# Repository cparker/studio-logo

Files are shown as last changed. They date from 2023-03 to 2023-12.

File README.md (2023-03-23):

# Studio Technology Logo

A 3D printed model of the Disney Studio Technology Logo.  Uses individually addressible WS2812B LEDs and an ESP32 microcontroller.

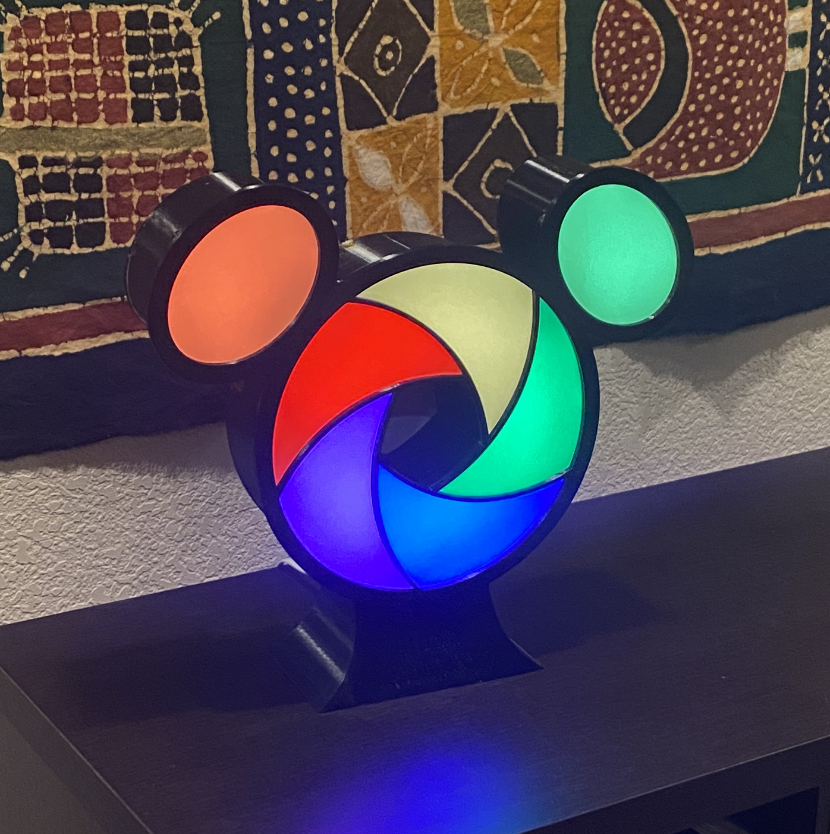
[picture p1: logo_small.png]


## Parts
* vellum (tracing paper) to diffuse the LEDs https://amzn.to/3JvHVWc 
* magnets : Holds the covers on https://amzn.to/3FLLyq5
* LED strips : [AliExpress](https://www.aliexpress.us/item/3256803346805677.html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)
* ESP32 microcontroller : [AliExpress](https://www.aliexpress.us/item/2251832622236364.html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)
* sticker paper : for the inside https://amzn.to/3Zb8XZ1  (or just glue regular white paper)

Parts to Print
* 1x [main frame](./cad/frame.stl)
* 1x [front cover](./cad/studio-logo-face.stl)
* 1x [stand](./cad/studio-logo-stand.stl)
* 1x [L Ear](./cad/ear-L.stl)
* 1x [R Ear](./cad/ear-r.stl)
* 1x [L Ear Cover](./cad/studio-logo-ear-cover-l.stl)
* 1x [R Ear Cover](./cad/studio-logo-ear-cover-r.stl)
* 1x [L Ear Bracket](./cad/studio-logo-ear-brack-l.stl)
* 1x [R Ear Bracket](./cad/studio-logo-ear-brack-r.stl)
* 5x [LED Brackets](./cad/led_bracket.stl)

Optionally print the backs (looks much better with the backs on)
* 1x [back cover](./cad/frame_back.stl)
* 3x [frame back mounts](./cad/main-back-mounts.stl)
* 1x [L ear back](./cad/studio-logo-ear-back-L.stl)
* 1x [R ear back](./cad/studio-logo-ear-back-r.stl)
* 4x [ear back mounts](./cad/ear-back-mount.stl)

Cut sticker paper to fit and line the inside or glue white paper to the inside.  This will help diffuse the light.

Glue magnets into the holes for attaching the front and back covers.  For glueing the magnets I use E6000 https://amzn.to/3ndiRvU .

Cut and glue vellum to the inside of the front cover and ear covers.

Glue the LED strip brackets to the inside of the frame (see cad model photos for guidence)

Wire up the LEDs and ESP32

Mount the LED strips to the brackets (hot glue or screws)

Upload the code to the ESP32

CAD model front
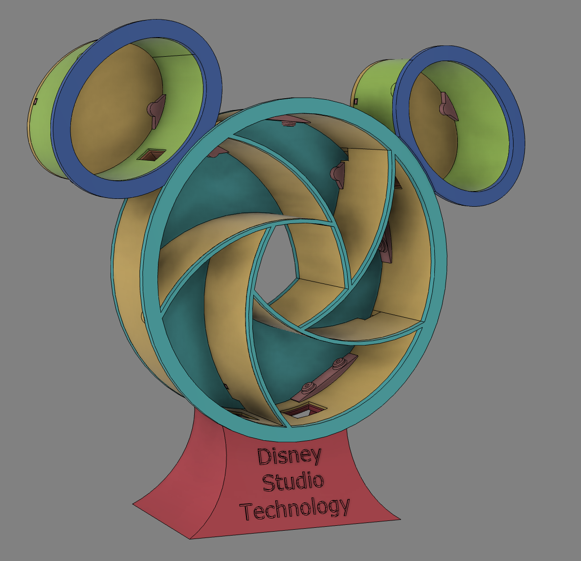
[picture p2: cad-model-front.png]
cad model front

CAD model back
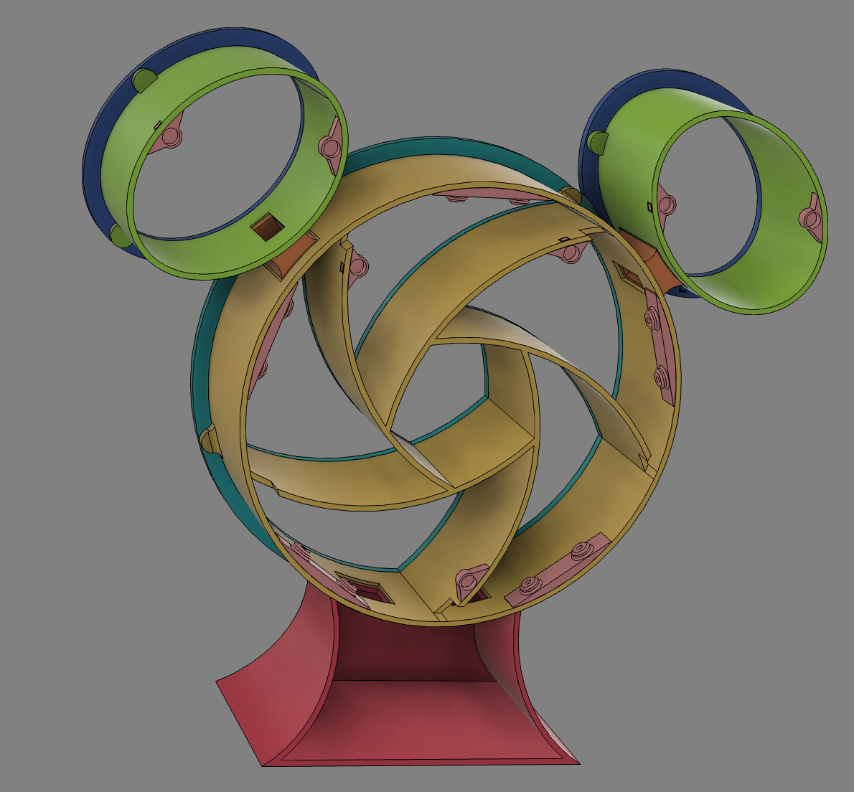
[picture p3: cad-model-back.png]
cad model front


CAD model video</br>

CAD model video (https://youtu.be/u030uRLA1Uc)

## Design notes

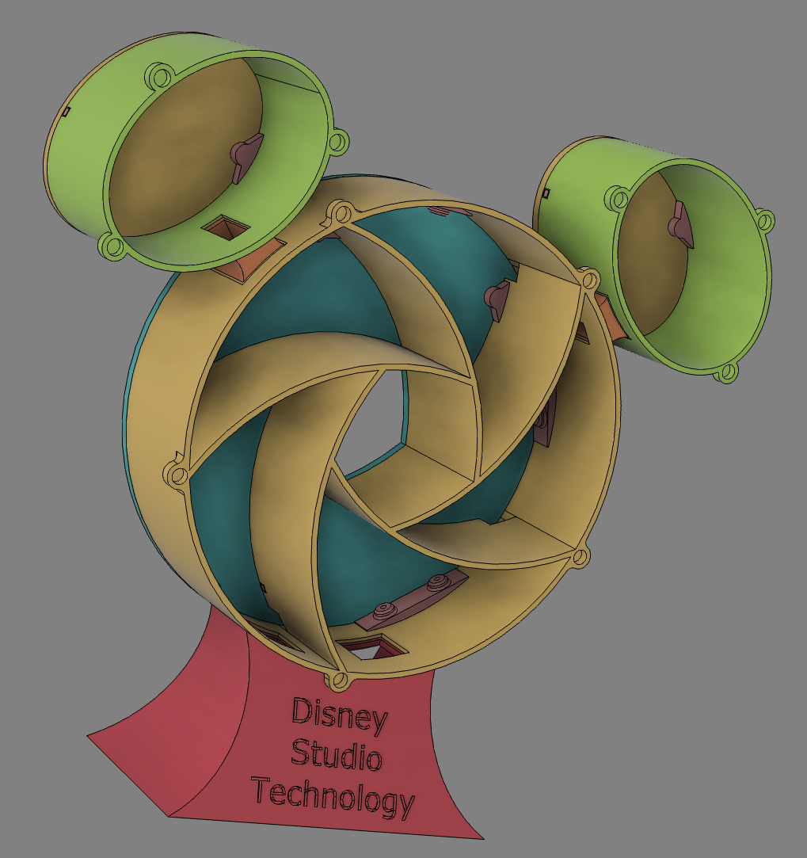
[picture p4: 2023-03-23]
cad-model-front-2.png

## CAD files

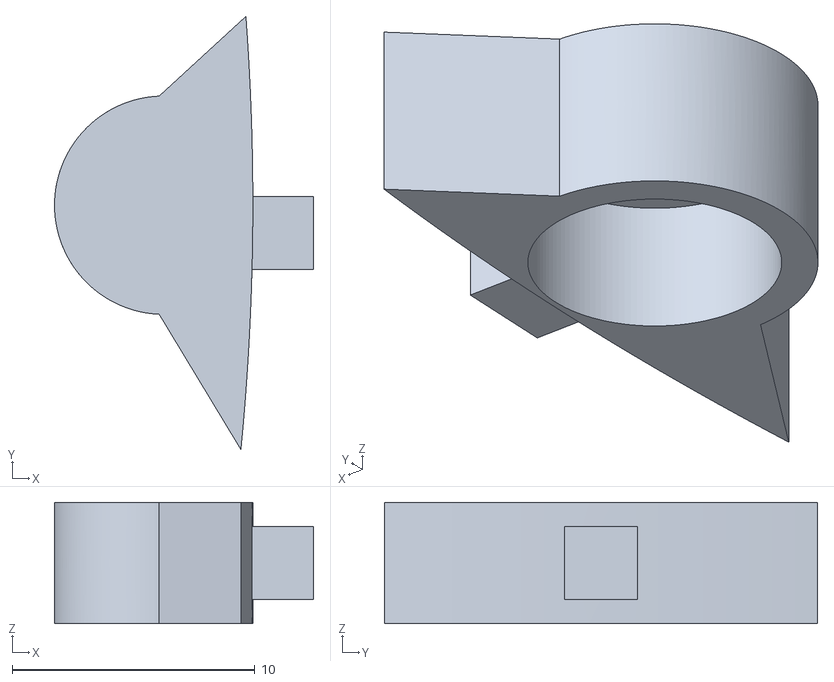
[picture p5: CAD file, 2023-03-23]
cad/main-back-mounts.stl
10.7 x 17.9 x 5.00

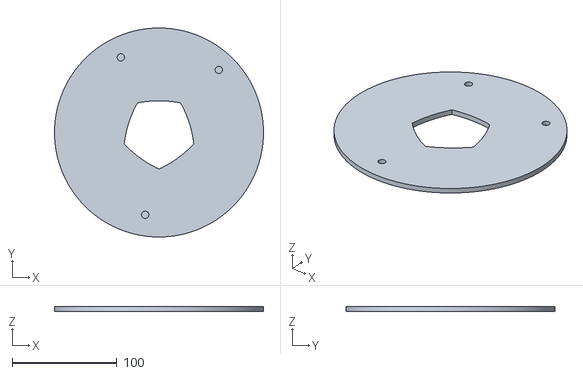
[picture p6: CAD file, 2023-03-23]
cad/frame_back.stl
200.0 x 200.0 x 4.50

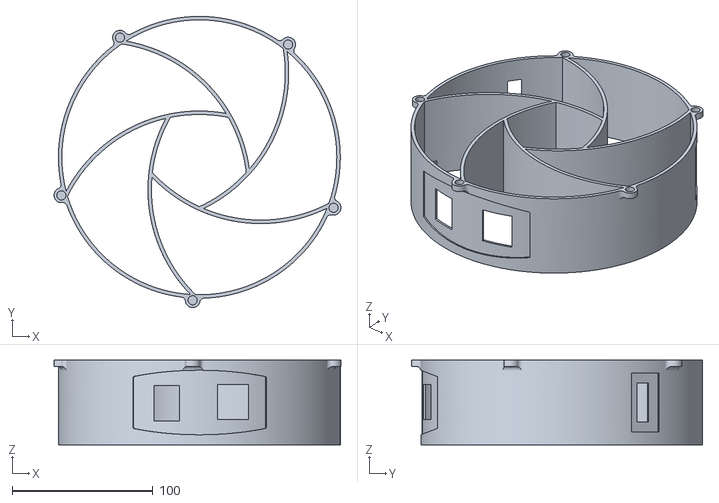
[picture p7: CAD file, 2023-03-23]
cad/frame.stl
203.6 x 206.6 x 60.0

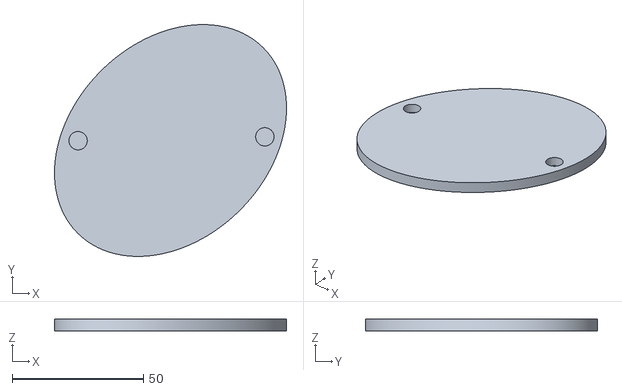
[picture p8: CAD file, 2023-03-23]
cad/studio-logo-ear-back-L.stl
88.4 x 88.3 x 4.50

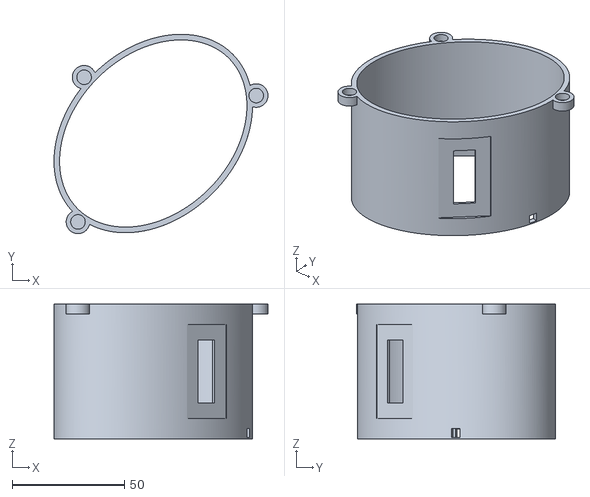
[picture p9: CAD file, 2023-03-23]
cad/ear-L.stl
95.3 x 88.8 x 60.0

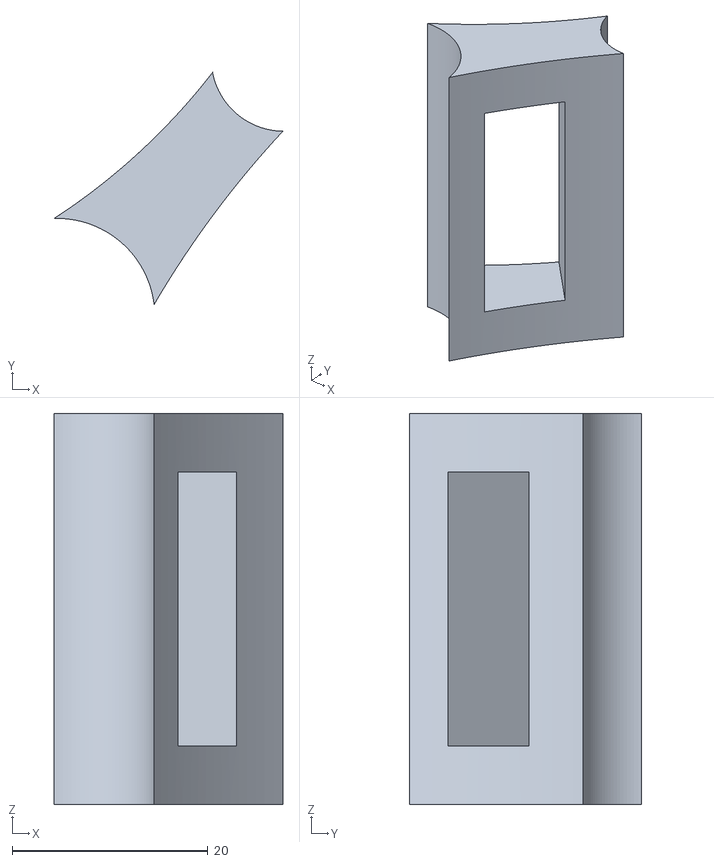
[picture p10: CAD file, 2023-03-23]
cad/studio-logo-ear-brack-l.stl
23.4 x 23.7 x 40.0

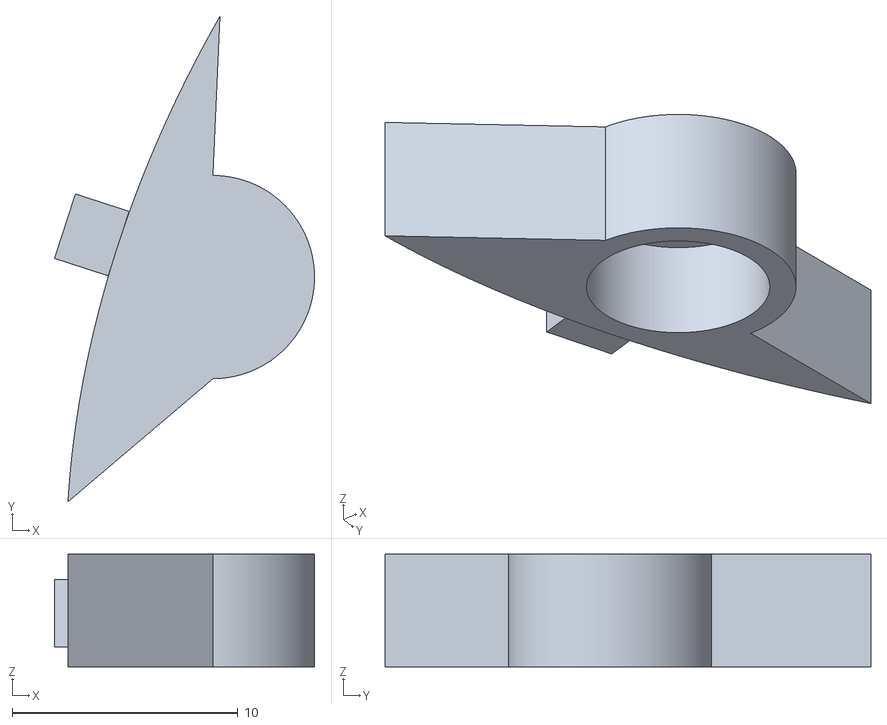
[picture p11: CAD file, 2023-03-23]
cad/ear-back-mount.stl
11.5 x 21.5 x 5.00

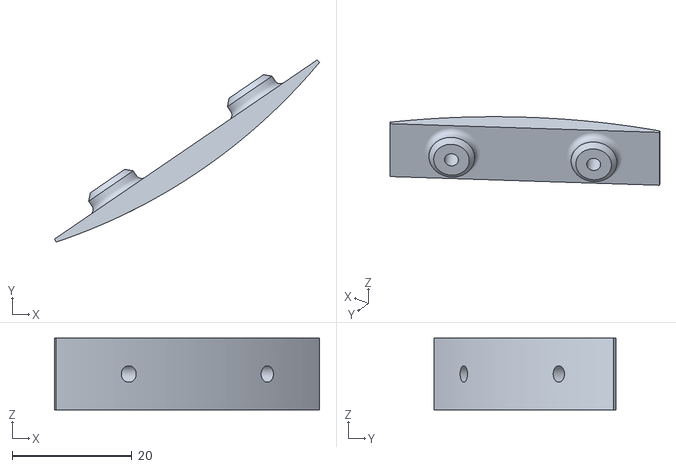
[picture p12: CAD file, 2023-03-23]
cad/led_bracket.stl
44.2 x 30.4 x 12.0

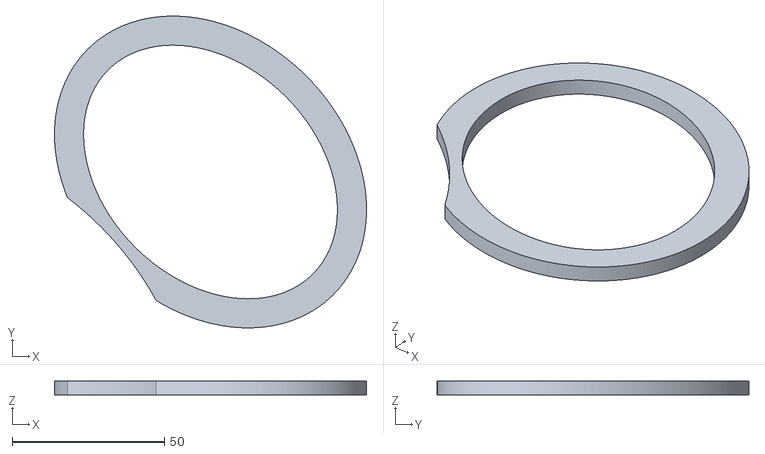
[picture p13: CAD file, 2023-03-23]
cad/studio-logo-ear-cover-r.stl
102.6 x 102.5 x 4.50

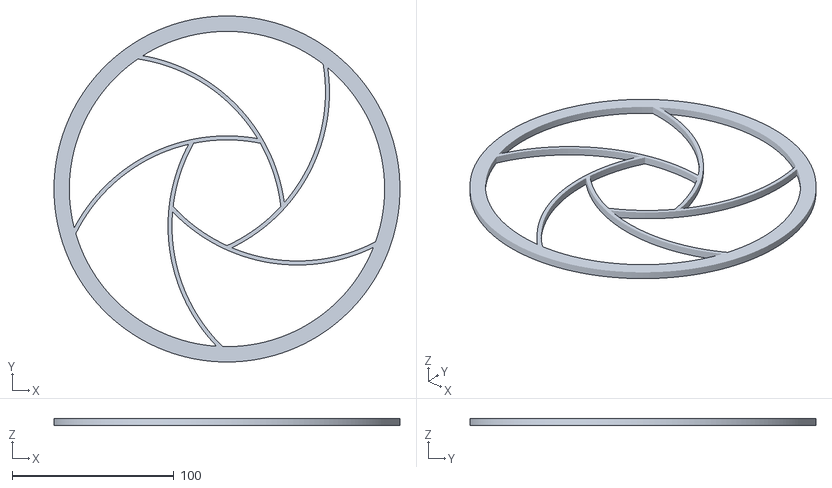
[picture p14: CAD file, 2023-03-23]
cad/studio-logo-face.stl
214.0 x 214.0 x 4.50

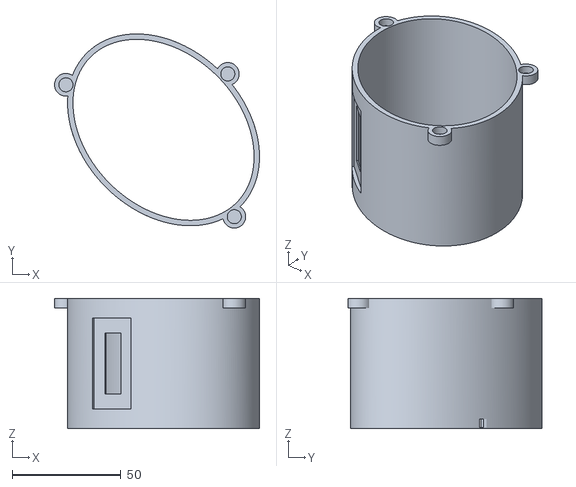
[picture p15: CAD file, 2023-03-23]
cad/ear-r.stl
94.4 x 89.4 x 60.0

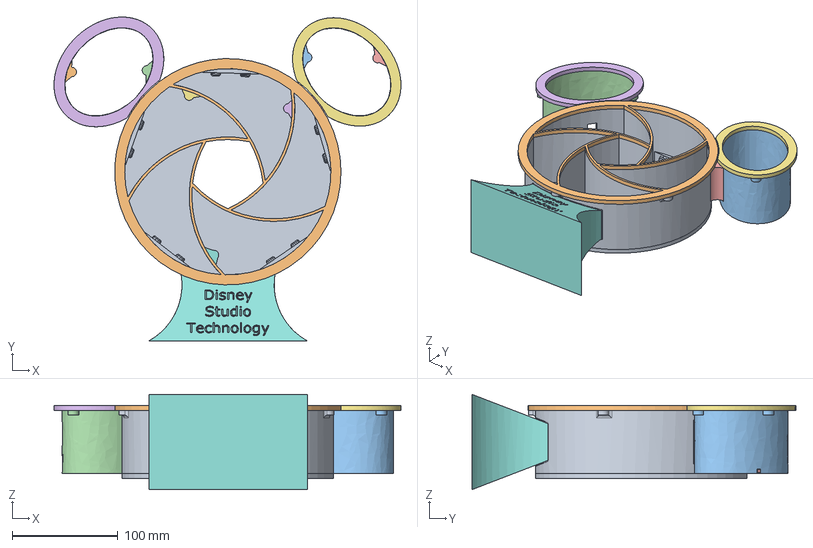
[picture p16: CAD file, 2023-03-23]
cad/studio tech logo.step
328.1 x 306.2 x 90.0 mm
frame
ears
ear brackets
ear covers
stand
led_brackets
back panel mounts
frame back

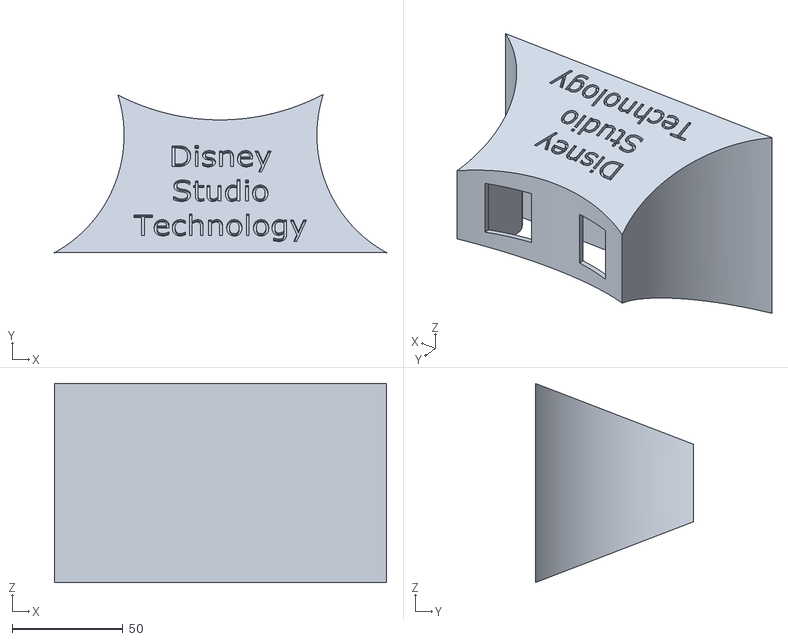
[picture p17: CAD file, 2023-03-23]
cad/studio-logo-stand.stl
150.0 x 71.6 x 90.0

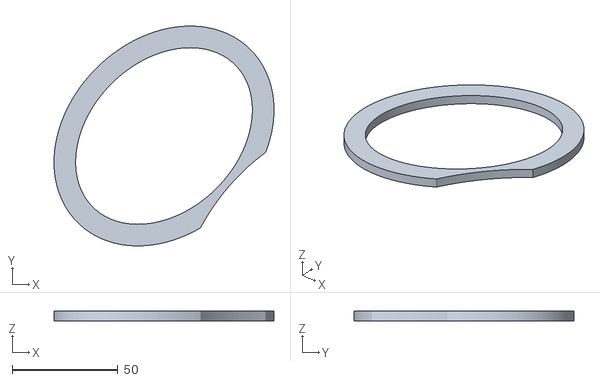
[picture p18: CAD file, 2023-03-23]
cad/studio-logo-ear-cover-l.stl
103.9 x 103.8 x 4.50

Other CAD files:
cad/studio-logo-ear-brack-r.stl
cad/studio-logo-ear-back-r.stl

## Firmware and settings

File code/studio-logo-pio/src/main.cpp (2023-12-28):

#include <ArduinoJson.h>
#include <FastLED.h>
#include <Preferences.h>
#include <PubSubClient.h>
#include <WiFi.h>

#include <algorithm>
#include <map>
#include <string>
#include <vector>

#include "ColorTransition.h"
#include "secrets.h"

// Create an instance of the Preferences library
Preferences preferences;

const int mqtt_port = 1883;

const char* appName = "studio-logo";

// mqtt topic for receiving mode changes
const char* mqtt_topic_mode = "studio-logo/mode";

// mqtt topic for receiving color palette changes
const char* mqtt_topic_palette = "studio-logo/palette";

// LED settings
#define NUM_LEDS 44
#define DATA_PIN 5  // Change this to the GPIO pin you've connected the LEDs to
#define LED_TYPE WS2812B
#define COLOR_ORDER GRB

// this is where state of each LED is stored
CRGB myleds[NUM_LEDS];

// some simple color definitions
CRGB blue(0, 0, 255);
CRGB green(0, 255, 0);
CRGB lighterGreen(20, 255, 20);
CRGB yellow(255, 255, 0);
CRGB red(255, 0, 0);
CRGB orange(255, 165, 0);
CRGB purple(128, 0, 128);
CRGB white(255, 255, 255);

struct LEDSection {
  int firstLEDIndex;
  int lastLEDIndex;
  float brightness;
};

const std::string mainSectionNamesAntiClock[] = {
    "section01", "section02", "section03", "section04", "section05"};

const float defaultMainSectionBrightness = 0.25;
const float defaultEarSectionBrightness = 1.0;

std::map<std::string, LEDSection> namedSections = {
    {"section01", {0, 7, defaultMainSectionBrightness}},
    {"section02", {8, 15, defaultMainSectionBrightness}},
    {"rightEar", {16, 17, defaultEarSectionBrightness}},
    {"section03", {18, 25, defaultMainSectionBrightness}},
    {"section04", {26, 33, defaultMainSectionBrightness}},
    {"leftEar", {34, 35, defaultEarSectionBrightness}},
    {"section05", {36, 43, defaultMainSectionBrightness}},
};

/*
 0 still
 1 cycle right
 2 cycle left
*/
uint8_t mode = 0;

std::map<std::string, CRGB> namedColors = {
    {"blue", blue},     {"green", green}, {"lighterGreen", lighterGreen},
    {"yellow", yellow}, {"red", red},     {"orange", orange},
    {"purple", purple}, {"white", white},
};

// maintain state of sections to color name, separate from the real state in
// myleds
std::map<std::string, std::string> currentSectionColors = {};

// define the anti-clockwise color rotation order for the main sections (not
// ears)
const uint8_t mainSectionCount = 5;
const std::string mainSectionAntiClockColorOrder[] = {"blue", "green", "yellow",
                                                      "red", "purple"};

// define the ear color rotation (L to R)
const std::string earColorOrder[] = {"orange", "lighterGreen"};

// the amount of ms that the color transition should take
const uint32_t transitionDuration = 500;

// how often the color changes in ms
const uint32_t transitionInterval = 10000;

uint32_t lastTransitionTime = 0;

WiFiClient espClient;
PubSubClient mqttClient(espClient);

void setupWifi() {
  delay(10);

  // Indicate Wi-Fi connection status
  myleds[0] = CRGB::Red;
  FastLED.show();

  // Connect to Wi-Fi
  WiFi.begin(ssid, password);
  while (WiFi.status() != WL_CONNECTED) {
    delay(1000);
    Serial.println("Connecting to Wi-Fi...");
  }
  Serial.println("Connected to Wi-Fi");
  Serial.print("IP address: ");
  Serial.println(WiFi.localIP());

  // Indicate successful Wi-Fi connection
  myleds[0] = CRGB::Green;
  FastLED.show();
  delay(5000);
}

void saveMode() {
  preferences.begin(appName, false);
  preferences.putUChar("mode", mode);
  preferences.end();
  Serial.print("Saved mode value to NVS: ");
  Serial.println(mode);
}

void saveCurrentSectionColors() {
  preferences.begin(appName, false);
  for (const auto& entry : currentSectionColors) {
    std::string sectionName = entry.first;
    std::string colorName = entry.second;
    preferences.putString(sectionName.c_str(), colorName.c_str());
  }
  preferences.end();
  Serial.println("Saved currentSectionColors to NVS");
}

void restoreCurrentSectionColors() {
    preferences.begin(appName, false);

    // Create a temporary key list to avoid modifying the map while iterating over it
    std::vector<std::string> keys;
    for (const auto& entry : currentSectionColors) {
        keys.push_back(entry.first);
    }

    // Iterate over the temporary key list
    for (const auto& sectionName : keys) {
        // Get the color name as an Arduino String
        String colorNameStr = preferences.getString(sectionName.c_str(), "");

        // Convert Arduino String to std::string
        std::string colorName(colorNameStr.c_str());

        // Update the map with the std::string
        currentSectionColors[sectionName] = colorName;
    }

    preferences.end();
    Serial.println("Restored currentSectionColors from NVS");
}

void mqttCallback(char* topic, byte* payload, unsigned int length) {
  // Convert the payload to a string for JSON parsing
  char message[length + 1];
  strncpy(message, (char*)payload, length);
  message[length] = '\0';  // Null-terminate the string

  // Debug print the topic and payload
  Serial.print("Received a message on topic: ");
  Serial.println(topic);
  Serial.print("Payload: ");
  Serial.println(message);

  // Use ArduinoJson to parse the payload
  StaticJsonDocument<200> doc;  // Adjust size as needed
  DeserializationError error = deserializeJson(doc, message);

  // Check for errors in deserialization
  if (error) {
    Serial.print("deserializeJson() failed: ");
    Serial.println(error.c_str());
    return;
  }

  // Handle different topics
  if (strcmp(topic, "studio-logo/mode") == 0) {
    // Extract the mode value
    int localMode = doc["mode"];  // Assumes mode is an integer
    Serial.print("Mode received: ");
    Serial.println(localMode);
    mode = localMode;
    saveMode();

    // Handle mode change here
    // ...
  } else if (strcmp(topic, "studio-logo/palette") == 0) {
    // Variables to store the color of each section
    const char* sectionColors[7];

    // Extract colors for each section
    sectionColors[0] = doc["section01"];
    sectionColors[1] = doc["section02"];
    sectionColors[2] = doc["section03"];
    sectionColors[3] = doc["section04"];
    sectionColors[4] = doc["section05"];
    sectionColors[5] = doc["leftEar"];
    sectionColors[6] = doc["rightEar"];

    currentSectionColors["section01"] = sectionColors[0];
    currentSectionColors["section02"] = sectionColors[1];
    currentSectionColors["section03"] = sectionColors[2];
    currentSectionColors["section04"] = sectionColors[3];
    currentSectionColors["section05"] = sectionColors[4];
    currentSectionColors["leftEar"] = sectionColors[5];
    currentSectionColors["rightEar"] = sectionColors[6];

    // Save the current section colors to NVS
    saveCurrentSectionColors();
  }
}

void restoreMode() {
  preferences.begin(appName, false);
  mode = preferences.getUChar("mode", 0);
  preferences.end();
  Serial.print("Loaded mode value from NVS: ");
  Serial.println(mode);
}

void setSectionToColorByName(std::string sectionName, CRGB color) {
  LEDSection section = namedSections[sectionName];
  int firstLED = section.firstLEDIndex;
  int lastLED = section.lastLEDIndex;
  int count = lastLED - firstLED + 1;
  float brightness = section.brightness;

  // Scale down the R, G, and B values by the brightness factor
  CRGB adjustedColor =
      CRGB(round(color.r * brightness), round(color.g * brightness),
           round(color.b * brightness));

  // Set the color of the specified range of LEDs
  fill_solid(myleds + firstLED, count, adjustedColor);

  // Serial.print("Set section ");
  // Serial.print(sectionName.c_str());
  // Serial.print(" to color ");
  // printCRGB(adjustedColor);
  // Serial.println();
}

void setStartupColors() {
  // for each color name in mainSectionAntiClockColorOrder
  for (int i = 0; i < mainSectionCount; i++) {
    // get the color name
    std::string colorName = mainSectionAntiClockColorOrder[i];
    // get the color
    CRGB color = namedColors[colorName];

    std::string sectionName = mainSectionNamesAntiClock[i];
    // set the section to the color
    setSectionToColorByName(sectionName, color);

    // update currentSectionColors
    currentSectionColors[sectionName] = colorName;
  }

  // do the same for the ears
  for (int i = 0; i < 2; i++) {
    const std::string earSections[] = {"leftEar", "rightEar"};
    std::string colorName = earColorOrder[i];
    CRGB color = namedColors[colorName];
    std::string sectionName = earSections[i];
    setSectionToColorByName(sectionName, color);
    currentSectionColors[sectionName] = colorName;
  }
}

// void setChristmasColors() {
//   currentSectionColors["section01"] = "white";
//   currentSectionColors["section02"] = "green";
//   currentSectionColors["section03"] = "red";
//   currentSectionColors["section04"] = "green";
//   currentSectionColors["section05"] = "red";
//   currentSectionColors["leftEar"] = "green";
//   currentSectionColors["rightEar"] = "red";
// }

void applyCurrentSectionColors() {
  for (const auto& entry : currentSectionColors) {
    std::string sectionName = entry.first;
    std::string colorName = entry.second;
    CRGB color = namedColors[colorName];
    setSectionToColorByName(sectionName, color);
  }
}

void setup() {
  Serial.begin(115200);
  FastLED.addLeds<LED_TYPE, DATA_PIN, COLOR_ORDER>(myleds, NUM_LEDS)
      .setCorrection(TypicalLEDStrip);
  randomSeed(analogRead(0));

  // limit my draw to 1A at 5v of power draw
  FastLED.setMaxPowerInVoltsAndMilliamps(5, 1000);

  setupWifi();

  mqttClient.setServer(mqtt_server, mqtt_port);
  mqttClient.setCallback(mqttCallback);

  setStartupColors();
  restoreMode();
}

void mqttReconnect() {
  while (!mqttClient.connected()) {
    Serial.print("Attempting MQTT connection...");
    if (mqttClient.connect("ESP32Client")) {
      Serial.println("connected");
      mqttClient.subscribe(mqtt_topic_mode);
      mqttClient.subscribe(mqtt_topic_palette);
    } else {
      Serial.print("failed, rc=");
      Serial.print(mqttClient.state());
      Serial.println(" try again in 5 seconds");
      delay(5000);
    }
  }
}

// struct ColorTransition {
//   std::string sectionName;
//   CRGB startColor;
//   CRGB endColor;
// };

void transitionColors(const std::vector<ColorTransition>& transitions,
                      uint32_t duration) {
  uint32_t startTime = millis();
  uint32_t elapsedTime = 0;
  float ratio;

  // Serial.println("--");
  // Serial.println("--");
  // Serial.println("START");
  while (elapsedTime < duration) {
    elapsedTime = millis() - startTime;
    ratio = (float)elapsedTime / (float)duration;

    for (const auto& transition : transitions) {
      LEDSection section = namedSections[transition.sectionName];

      // if (transition.sectionName == "section02") {
      //   Serial.print("Transitioning section ");
      //   Serial.print(transition.sectionName.c_str());
      //   Serial.print(" from ");
      //   printCRGB(transition.startColor);
      //   Serial.print(" to ");
      //   printCRGB(transition.endColor);
      //   Serial.print(" at ratio ");
      //   Serial.println(ratio);
      // }

      CRGB currentColor;
      if (ratio < 1.00) {
        currentColor.r =
            transition.startColor.r +
            (transition.endColor.r - transition.startColor.r) * ratio;
        currentColor.g =
            transition.startColor.g +
            (transition.endColor.g - transition.startColor.g) * ratio;
        currentColor.b =
            transition.startColor.b +
            (transition.endColor.b - transition.startColor.b) * ratio;
      } else {
        currentColor = transition.endColor;
      }

      // if (transition.sectionName == "section02") {
      //   Serial.print("Current color: ");
      //   printCRGB(currentColor);
      //   Serial.println();
      // }

      // for (int i = section.firstLEDIndex; i <= section.lastLEDIndex; ++i) {
      //   // Set the currentColor for each LED in the specified section
      //   myleds[i] = currentColor;
      // }
      setSectionToColorByName(transition.sectionName, currentColor);
    }

    FastLED.show();
    FastLED.delay(
        5);  // You can adjust the delay for smoother/faster transitions
  }
  // Serial.println("section02 is now");
  // for (int i = namedSections["section02"].firstLEDIndex; i <=
  // namedSections["section02"].lastLEDIndex; ++i) {
  //   // Set the currentColor for each LED in the specified section
  //   printCRGB(myleds[i]);
  // }

  // Serial.println("--");
  // Serial.println("--");
  // Serial.println("END");
}

int findColorIndex(const std::string& colorName) {
  // Find the iterator pointing to the color name in the array
  const auto it =
      std::find(std::begin(mainSectionAntiClockColorOrder),
                std::end(mainSectionAntiClockColorOrder), colorName);

  // Check if the color was found
  if (it != std::end(mainSectionAntiClockColorOrder)) {
    // Return the index of the found color
    return std::distance(std::begin(mainSectionAntiClockColorOrder), it);
  } else {
    // Return -1 if the color was not found
    return -1;
  }
}

void printCRGB(const CRGB& color) {
  Serial.print("R: ");
  Serial.print(color.r);
  Serial.print(", G: ");
  Serial.print(color.g);
  Serial.print(", B: ");
  Serial.print(color.b);
}

void rotateColors(bool antiClockwise) {
  // Create a vector to store the ColorTransition objects
  std::vector<ColorTransition> transitions;

  std::map<std::string, std::string> newColorsBySection = {};

  for (const auto& sectionName : mainSectionNamesAntiClock) {
    // create a ColorTransition for section1
    ColorTransition sectionTransition;
    sectionTransition.sectionName = sectionName;
    std::string startColorName = currentSectionColors[sectionName];
    // get the index of the current color in the mainSectionAntiClockColorOrder
    int currentIndex = findColorIndex(startColorName);
    // next index of color in mainSectionAntiClockColorOrder
    // int nextIndex = (currentIndex - 1) % mainSectionCount;
    int nextIndex = -1;
    if (antiClockwise) {
      nextIndex = currentIndex == 0 ? mainSectionCount - 1 : currentIndex - 1;
    } else {
      nextIndex = (currentIndex + 1) % mainSectionCount;
    }
    // get the next color name
    std::string nextColorName = mainSectionAntiClockColorOrder[nextIndex];

    // next color value
    CRGB startColor = namedColors[startColorName];
    CRGB nextColor = namedColors[nextColorName];
    sectionTransition.startColor = startColor;
    sectionTransition.endColor = nextColor;

    newColorsBySection[sectionName] = nextColorName;

    Serial.print("Transitioning section ");
    Serial.print(sectionTransition.sectionName.c_str());
    Serial.print(" from ");
    Serial.print(startColorName.c_str());
    Serial.print(" ");
    printCRGB(sectionTransition.startColor);
    Serial.print(", to ");
    Serial.print(nextColorName.c_str());
    Serial.print(" ");
    printCRGB(sectionTransition.endColor);
    Serial.println();

    // add the transition to the vector
    transitions.push_back(sectionTransition);
  }

  // now transition the colors
  transitionColors(transitions, transitionDuration);

  // after the transition, update the currentSectionColors from
  // newColorsBySection
  currentSectionColors = newColorsBySection;
}

void printAllLEDColors(const CRGB* leds, int numLEDs) {
  for (int i = 0; i < numLEDs; i++) {
    Serial.print("LED ");
    Serial.print(i);
    Serial.print(": ");
    printCRGB(leds[i]);
    Serial.println();
  }
}

void printCurrentSectionColors(
    const std::map<std::string, std::string>& currentSectionColors) {
  for (const auto& entry : currentSectionColors) {
    Serial.print("Section: ");
    Serial.print(entry.first.c_str());
    Serial.print(", Color: ");
    Serial.println(entry.second.c_str());
  }
}

void doTransition(int mode) {
  // Determine what to do based on the mode
  Serial.print("transitioning for mode: ");
  Serial.println(mode);
  switch (mode) {
    case 0:
      setStartupColors();
      break;
    case 1:
      restoreCurrentSectionColors();
      applyCurrentSectionColors();
      break;
    case 2:
      rotateColors(false);
      break;
    case 3:
      rotateColors(true);
      break;
    default:
      break;
  }
}

int loopCount = 0;
void loop() {
  uint32_t currentTime = millis();

  if (currentTime - lastTransitionTime >= transitionInterval) {
    // Serial.println("before transition, current colors:");
    // printCurrentSectionColors(currentSectionColors);
    // Serial.println("leds before transition:");
    // printAllLEDColors(myleds, NUM_LEDS);
    // Serial.println("");

    doTransition(mode);

    // Serial.println("");

    // Serial.println("after transition , current colors:");
    // printCurrentSectionColors(currentSectionColors);
    // printAllLEDColors(myleds, NUM_LEDS);

    // printAllLEDColors(myleds, NUM_LEDS);
    lastTransitionTime = currentTime;
  }

  FastLED.show();
  FastLED.delay(10);  // 10 ms delay for smooth animation

  if (!mqttClient.connected()) {
    mqttReconnect();
  }

  mqttClient.loop();
}
